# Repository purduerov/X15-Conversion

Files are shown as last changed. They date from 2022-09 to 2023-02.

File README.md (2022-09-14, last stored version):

# Readme for X15-Conversion

Whenever you make a new part, download the datasheet and save it here _**and**_ with the part in the parts library

Always pull other people's changes before beginning to work
`git pull`

Be sure to push your changes after  working on them. Run:
1. `git add .` to add any files in this directory or a subdirectory
or `git add -u` to add any modified files
2. (Optional) `git clean -nX` to see what ignored files can be removed
	`git clean -fX` removes ignored files (Eagle backups)
3. `git commit -m "helpful commit message"` with a description of the work that you did
4. `git push` to push your work to github

Other helpful commands
* `git status` says information about modified and staged files
* `git log` shows the recent commits of the repository
* `git log filename.extension` show the recent commits for just that file
* `git checkout first-couple-letter-of-commit-id` lets you go back to a previous version
* `git checkout master` brings you back to the latest commit
* `git tag` lists the tags
* `git tag -a orderX -m "the version of the board placed for the X'th order"` tag a specific commit
* `git push --tags` needed to push tags to remote
* `git show orderX` show the commit log for the given tag
* `git checkout orderX` go back and interact with the files at the tagged commit

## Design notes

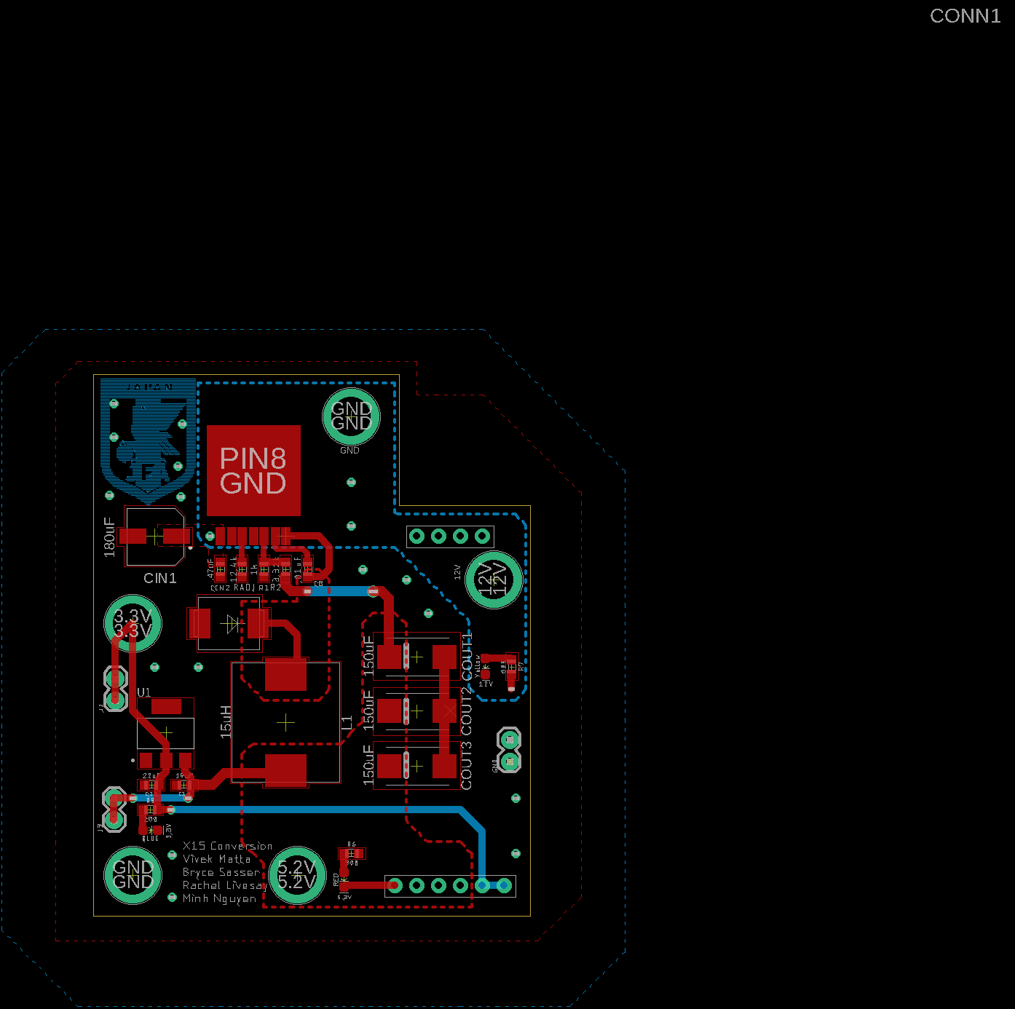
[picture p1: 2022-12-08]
x15conv.png

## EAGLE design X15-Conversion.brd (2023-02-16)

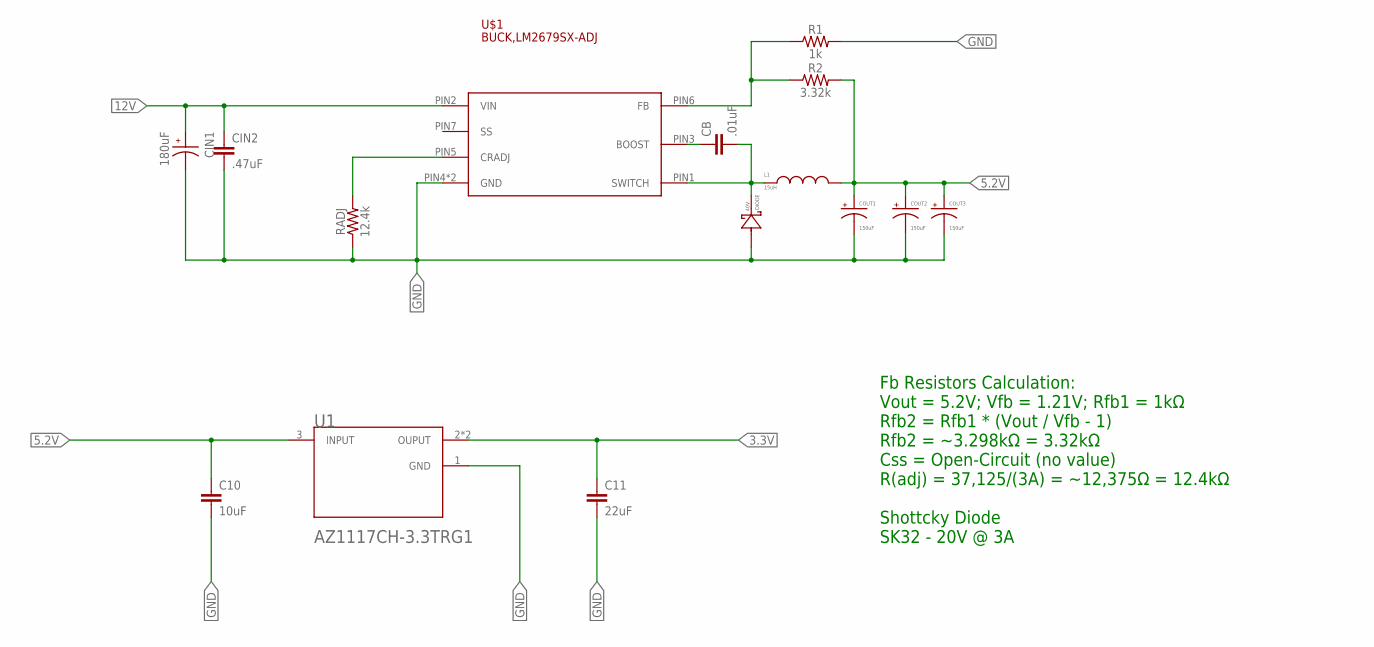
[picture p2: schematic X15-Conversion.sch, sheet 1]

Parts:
C10: 10uF; 0603
C11: 22uF; 0603
CB: .01uF; 0603
CIN1: 180uF; CAP_EEEFKE181XSP
CIN2: .47uF; 0603
COUT1, COUT2, COUT3: 150uF; 2917(7343-31-METRIC)
DIODE: 40V; DO214AC
L1: 15uH; HCMA1305
R1: 1k; 0603
R2: 3.32k; 0603
RADJ: 12.4k; 0603
U1: LINEAR,AZ1117CR-3.3TRG1DIODES_AZ1117CH-3.3TRG1_0_0; LINEAR,AZ1117CR-3.3TRG1
U$1: BUCK,LM2679SX-ADJ

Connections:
3.3V: C11.1, U1.2 (OUPUT), U1.4 (OUPUT); also elsewhere on the board
5.2V: C10.1, COUT1.+, COUT2.+, COUT3.+, L1.2, R2.2, U1.3 (INPUT); also elsewhere on the board
12V: CIN1.1, CIN2.1, U$1.PIN2 (VIN); also elsewhere on the board
BOOST: CB.1, U$1.PIN3 (BOOST)
CRADJ: RADJ.2, U$1.PIN5 (CRADJ)
FB: R1.1, R2.1, U$1.PIN6 (FB)
GND: C10.2, C11.2, CIN1.2, CIN2.2, COUT1.-, COUT2.-, COUT3.-, DIODE.A (2), R1.2, RADJ.1, U1.1 (GND), U$1.PIN4 (GND), U$1.PIN8 (GND); also elsewhere on the board
SWITCH: CB.2, DIODE.C (1), L1.1, U$1.PIN1 (SWITCH)

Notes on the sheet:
Fb Resistors Calculation: Vout = 5.2V; Vfb = 1.21V; Rfb1 = 1kΩ Rfb2 = Rfb1 * (Vout / Vfb - 1) Rfb2 = ~3.298kΩ = 3.32kΩ Css = Open-Circuit (no value) R(adj) = 37,125/(3A) = ~12,375Ω = 12.4kΩ Shottcky Diode SK32 - 20V @ 3A

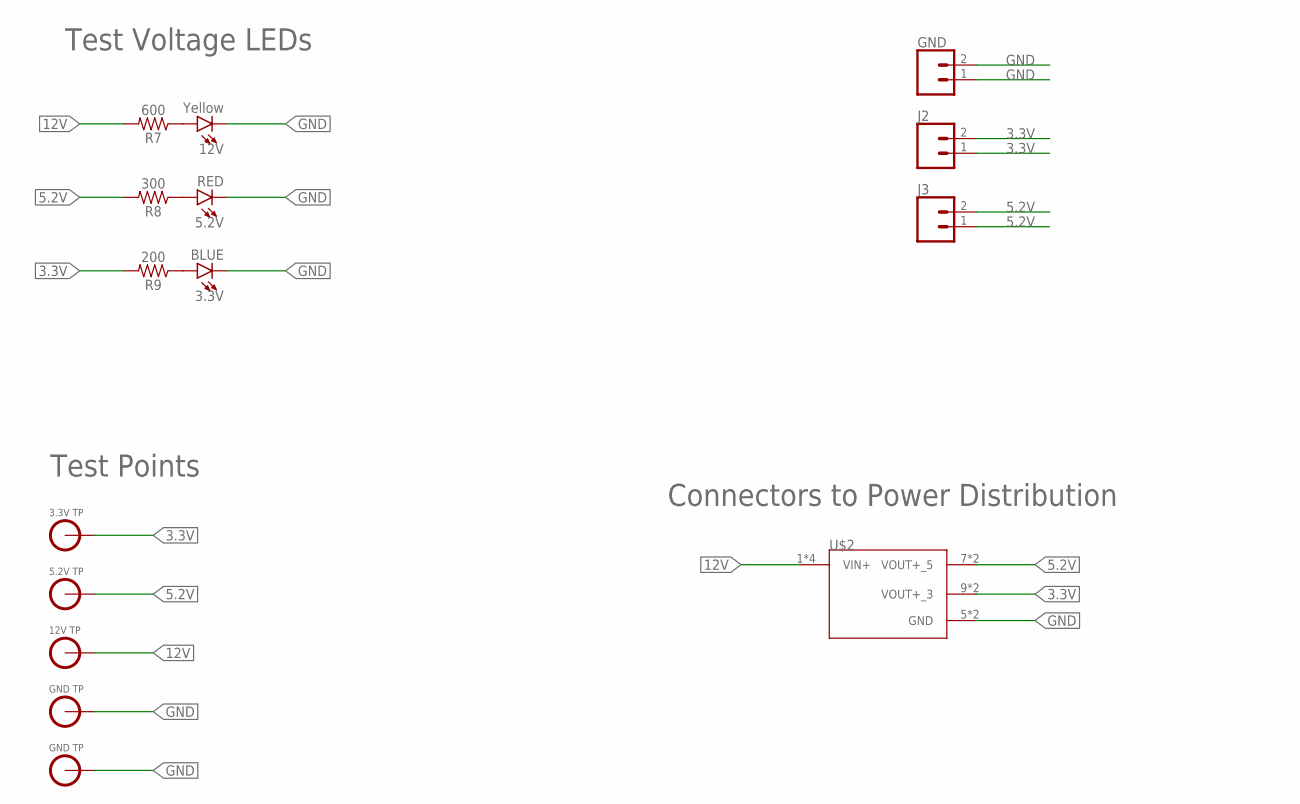
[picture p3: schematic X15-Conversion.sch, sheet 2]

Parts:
3.3V: BLUE; LED-0603
5.2V: RED; LED-0603
12V: Yellow; LED-0603
GND: CONN_02; 1X02
J2, J3: CONN_02; 1X02
R7: 600; 0603
R8: 300; 0603
R9: 200; 0603
U$2: CONVERSION-DISTRIBUTION; TSW-105-05-G-S(C-D)
U$8: 3.3V_TESTPOINT
U$9: 5.2V_TESTPOINT
U$10: 12V_TESTPOINT
U$11, U$12: GND_TESTPOINT

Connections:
3.3V: J2.1, J2.2, R9.2, U$2.9 (VOUT+_3), U$2.10 (VOUT+_3), U$8.3.3V; also elsewhere on the board
5.2V: J3.1, J3.2, R8.2, U$2.7 (VOUT+_5), U$2.8 (VOUT+_5), U$9.5.2V; also elsewhere on the board
12V: R7.2, U$2.1 (VIN+), U$2.2 (VIN+), U$2.3 (VIN+), U$2.4 (VIN+), U$10.12V; also elsewhere on the board
GND: 3.3V.C, 5.2V.C, 12V.C, GND.1, GND.2, U$2.5 (GND), U$2.6 (GND), U$11.GND, U$12.GND; also elsewhere on the board
unnamed: 12V.A, R7.1
unnamed: 5.2V.A, R8.1
unnamed: 3.3V.A, R9.1

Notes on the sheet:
Connectors to Power Distribution
Test Points
Test Voltage LEDs

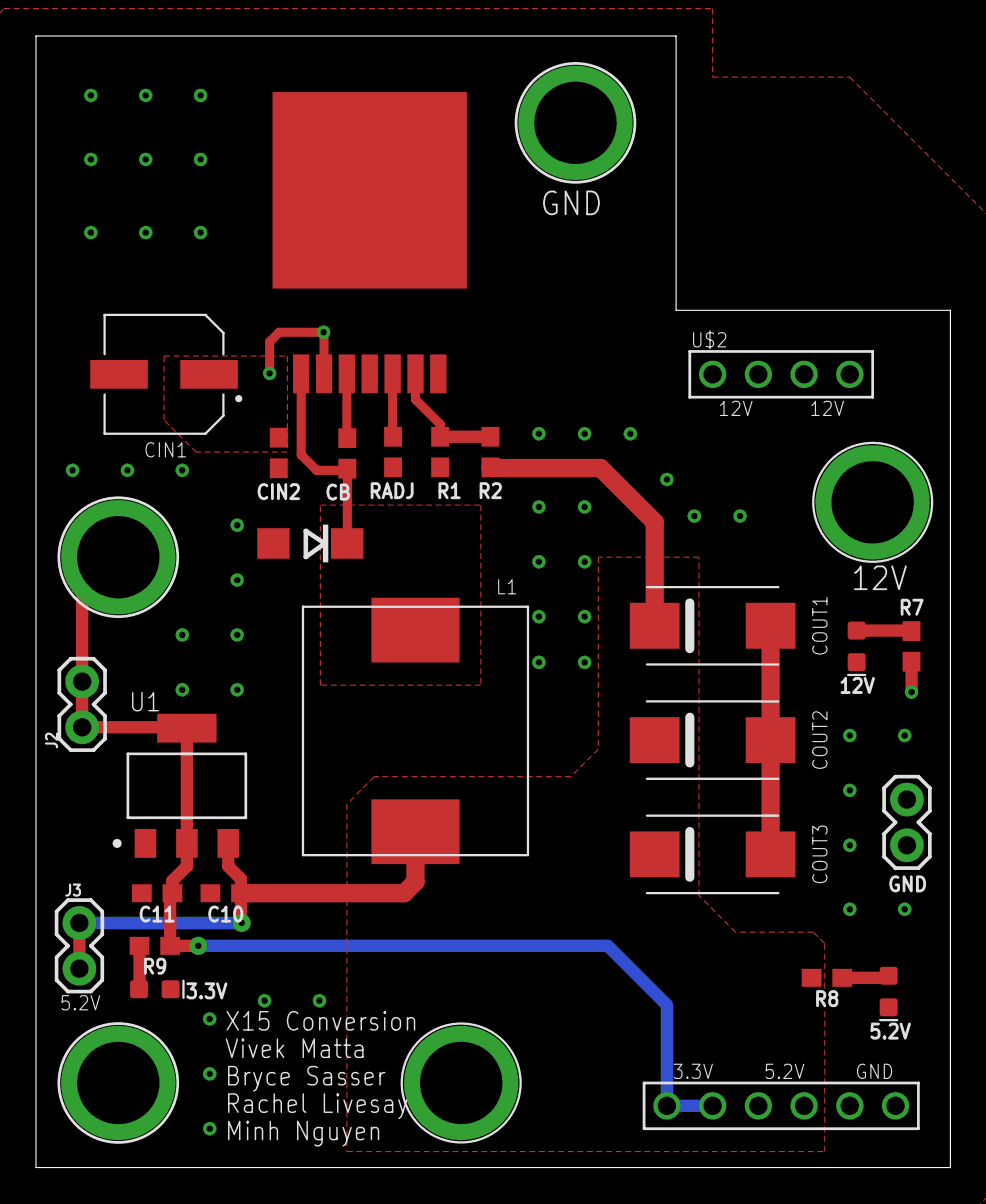
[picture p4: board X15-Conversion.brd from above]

Board: 2 copper layers, 50.8 x 62.9 mm, 30 parts (0 on the bottom side), 11 nets.

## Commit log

2022-09-21 Create X15-Conversion.sch
    First commit to ROV
    [X15-Conversion.sch]
2022-10-15 Board review submission
    [X15-Conversion.brd]
2022-10-15 Second commit to board review
    [X15-Conversion.sch]
2022-10-15 added some cool files
    [X15-Conversion.brd, X15-Conversion.sch]
2022-10-15 Changed the GND
    [X15-Conversion.brd, X15-Conversion.sch]
2022-10-18 board dimensions
    [X15-Conversion.brd]
2022-10-20 Changed the diode
    [X15-Conversion.sch]
2022-10-22 Fixed a lot of errors and debugged
    [X15-Conversion.brd]
2022-10-22 added wite
    [X15-Conversion.sch]
2022-10-22 deleted wire
    [X15-Conversion.sch]
2022-10-22 Revert "Merge branch 'master' of https://github.com/purduerov/X15-Conversion"
    This reverts commit 41817e178b7c3d64232767e30bfff53a28a489f7, reversing
    changes made to 9f5667108a341ebdd134b7c2334aa0d8aa0ab67e.
    [X15-Conversion.brd]
2022-10-22 Revert "Revert "Merge branch 'master' of https://github.com/purduerov/X15-Conversion""
    This reverts commit 3946a35888136fdb14d8eaf85822cd7069644279.
    [X15-Conversion.brd]
2022-10-22 Added on board
2022-10-27 Changed some compnoents
    [X15-Conversion.brd]
2022-11-02 deleted not good files
    [X15-Conversion.brd, X15-Conversion.sch]
2022-11-03 Added stuff to board
2022-11-05 Update Library
    [X15-Conversion.brd, X15-Conversion.sch]
2022-11-11 added some stuff to board
2022-11-11 Finalized Board for Review
    [X15-Conversion.brd]
2022-11-12 Edited suggestions given by Bryce
    [X15-Conversion.brd]
2022-11-12 Edited some minor adj
    [X15-Conversion.brd]
2022-11-12 Minh da best
    [X15-Conversion.brd]
2022-11-17 added test points
    [X15-Conversion.brd]
2022-11-30 Chenaged some cool stuff you know
    [X15-Conversion.brd]
2022-12-01 Changed size in VIA
    [X15-Conversion.brd]
2022-12-01 Changed the fonts
    [X15-Conversion.brd, X15-Conversion.sch]
2022-12-03 Changed some wires
    [X15-Conversion.brd]
2022-12-03 Added vias to ground
    [X15-Conversion.brd]
2022-12-03 Added images
    [X15-Conversion.brd]
2022-12-08 got rid of dash
    [X15-Conversion.brd]
2022-12-08 Added labels to the lights
    [X15-Conversion.brd, X15-Conversion.sch]
2023-02-16 changed pins
    [X15-Conversion.brd]
2023-02-16 Fix X15 Conversion
    [X15-Conversion.brd, X15-Conversion.sch]

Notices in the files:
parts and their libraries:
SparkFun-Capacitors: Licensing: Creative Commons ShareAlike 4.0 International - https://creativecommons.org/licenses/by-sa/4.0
